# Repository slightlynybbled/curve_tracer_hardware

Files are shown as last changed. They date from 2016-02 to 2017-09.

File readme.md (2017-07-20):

# Purpose #

The purpose of this repository is to document the curve tracer project.  A
full description may be found at [for(embed)](http://www.forembed.com/project-curve-tracer-requirements.html).

# Project Repositories #

Be sure to check out the [firmware](https://github.com/slightlynybbled/curve_tracer_firmware) and 
[gui](https://github.com/slightlynybbled/curve_tracer_gui) repositories!

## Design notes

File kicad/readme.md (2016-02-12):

# Electronics #

This directory contains the schematics and PCB layout (KiCad)

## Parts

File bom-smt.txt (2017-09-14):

Item	Qty	Reference	Manufacturer	MPN	Description	Datasheet	
1	13	 C1, C7, C8, C9, C10, C11, C12, C13, C14, C24, C25, C26, C27	Yageo	CC0603ZRY5V7BB104	capacitor, 100nF, 0603		
2	12	 C2, C4, C6, C15, C16, C17, C18, C19, C20, C21, C22, C23	Yageo	CC0603ZRY5V7BB105	capacitor, 1uF, 0603		
3	2	 C3, C5	Kemet	C0603C470J3GACTU	capacitor, 47pF, 0603		
5	1	 P2	JAE Electronics	DX4R005JJ2R1800	Conn USB Micro-B		
6	1	 P3	Molex	0022284020	header, 0.1in, 2-pos		
7	1	 P4	Assmann WSW Components	A06-LC-TT	DIP socket, 2x3		
10	6	 R1, R2, R3, R7, R16, R21	Yageo	RC0603FR-0710KL	resistor, 10kohm, 0603		
11	1	 R12	Yageo	RC0603FR-0710RL	resistor, 10ohm, 0603		
12	12	 R4, R5, R6, R8, R11, R13, R14, R15, R17, R18, R19, R20	Yageo	RC0603FR-071KL	resistor, 1kohm, 0603		
13	2	 R9, R10	Yageo	RC0603FR-0727RL	resistor, 27ohm, 0603		
14	1	 U1	Microchip	MCP6L04T-E/ST	Opamp 1MHz, Quad, TSSOP-14		
15	1	 U2	Microchip, Inc.	PIC24FV16KM202-I/SS	Microcontroller		
16	1	 U3	FTDI	FT230XS-R	USB-to-UART, IC, SSOP-16

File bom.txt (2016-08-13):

Item	Qty	Reference	Manufacturer	MPN	Description	Datasheet	
1	13	 C1, C7, C8, C9, C10, C11, C12, C13, C14, C24, C25, C26, C27	Yageo	CC0603ZRY5V7BB104	capacitor, 100nF, 0603		
2	12	 C2, C4, C6, C15, C16, C17, C18, C19, C20, C21, C22, C23	Yageo	CC0603ZRY5V7BB105	capacitor, 1uF, 0603		
3	2	 C3, C5	Kemet	C0603C470J3GACTU	capacitor, 47pF, 0603		
4	11	 P1, W2, W3, W1, W4, W5, W8, W9, P5, P9, P8			programming header		
5	1	 P2	JAE Electronics	DX4R005JJ2R1800	Conn USB Micro-B		
6	1	 P3	Molex	0022284020	header, 0.1in, 2-pos		
7	1	 P4	Assmann WSW Components	A06-LC-TT	DIP socket, 2x3		
8	1	 P6	B&K Precision	CT3150-2	jack, safety, red		
9	1	 P7	B&K Precision	CT3150-0	jack, safety, black		
10	6	 R1, R2, R3, R7, R16, R21	Yageo	RC0603FR-0710KL	resistor, 10kohm, 0603		
11	1	 R12	Yageo	RC0603FR-0710RL	resistor, 10ohm, 0603		
12	12	 R4, R5, R6, R8, R11, R13, R14, R15, R17, R18, R19, R20	Yageo	RC0603FR-071KL	resistor, 1kohm, 0603		
13	2	 R9, R10	Yageo	RC0603FR-0727RL	resistor, 27ohm, 0603		
14	1	 U1	Microchip	MCP6L04T-E/ST	Opamp 1MHz, Quad, TSSOP-14		
15	1	 U2	Microchip, Inc.	PIC24FV16KM202-I/SS	Microcontroller		
16	1	 U3	FTDI	FT230XS-R	USB-to-UART, IC, SSOP-16

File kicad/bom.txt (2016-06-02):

Item	Qty	Reference	Manufacturer	MPN	Description	Datasheet	
1	9	 C1, C7, C8, C9, C10, C11, C12, C13, C14	Yageo	CC0603ZRY5V7BB104	capacitor, 100nF, 0603		
2	12	 C2, C4, C6, C15, C16, C17, C18, C19, C20, C21, C22, C23	Yageo	CC0603ZRY5V7BB105	capacitor, 1uF, 0603		
3	2	 C3, C5	Kemet	C0603C470J3GACTU	capacitor, 47pF, 0603		
4	11	 P1, W2, W3, W6, W7, W1, W4, W5, W8, W9, W10					
5	1	 P2	JAE Electronics	DX4R005JJ2R1800	Conn USB Micro-B		
6	1	 P3	On Shore Technology, Inc.	OSTTC032162	terminal block, 5.08mm, 3pos		
7	1	 P4	Assmann WSW Components	A06-LC-TT	DIP socket		
8	5	 R1, R2, R3, R7, R16	Yageo	RC0603FR-0710KL	resistor, 10kohm, 0603		
9	1	 R12	Yageo	RC0603FR-0710RL	resistor, 10ohm, 0603		
10	8	 R4, R5, R6, R8, R11, R13, R14, R15	Yageo	RC0603FR-071KL	resistor, 1kohm, 0603		
11	2	 R9, R10	Yageo	RC0603FR-0727RL	resistor, 27ohm, 0603		
12	1	 U1	Microchip	MCP6L04T-I/ST	Opamp 1MHz, Quad, TSSOP-14		
13	1	 U2	Microchip, Inc.	PIC24FV16KM202	Microcontroller		
14	1	 U3	FTDI	FT230XS-R	USB-to-UART, IC, SSOP-16

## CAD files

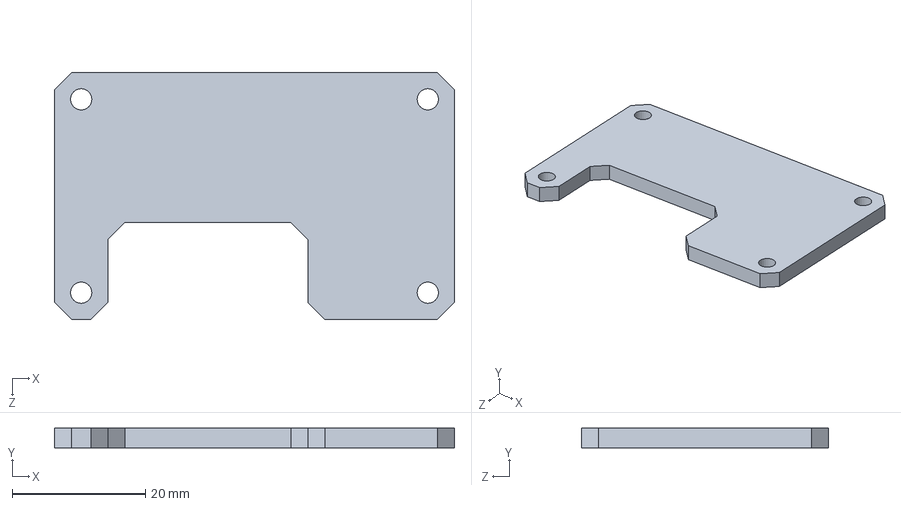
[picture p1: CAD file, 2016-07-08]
cad/solidworks/case_top.SLDPRT
60.0 x 3.00 x 37.0 mm

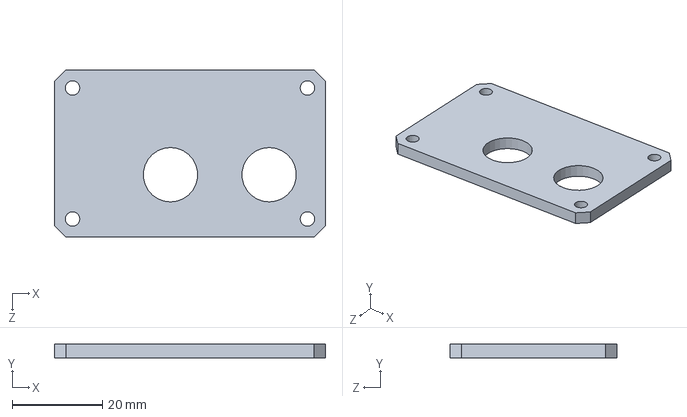
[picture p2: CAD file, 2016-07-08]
cad/solidworks/case_bottom.SLDPRT
60.0 x 3.00 x 37.0 mm

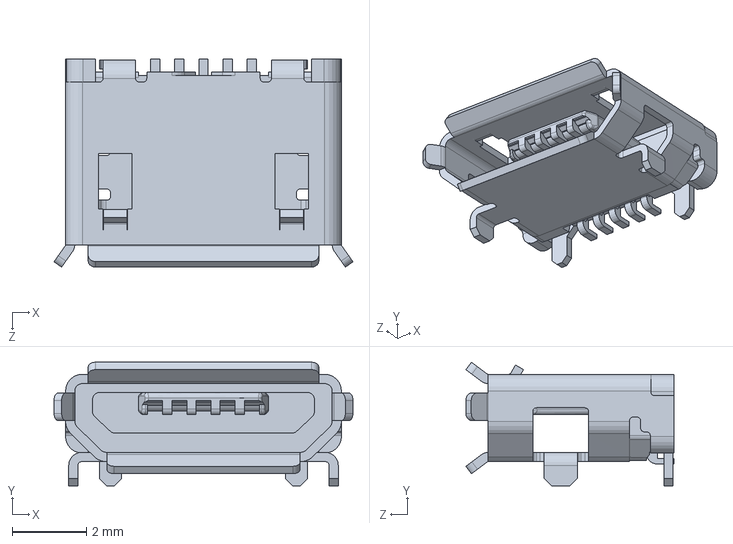
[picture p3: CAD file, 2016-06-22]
cad/solidworks/DX4R005JJ2R1800.SLDPRT
8.04 x 3.33 x 5.60 mm

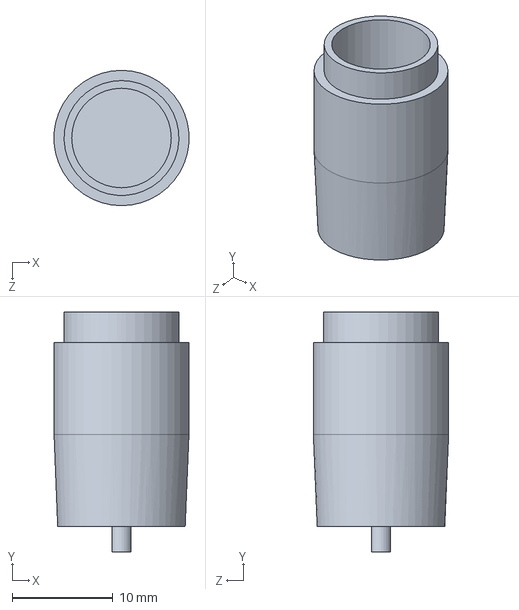
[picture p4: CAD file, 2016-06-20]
cad/solidworks/ct3150-0.SLDPRT
13.4 x 23.9 x 13.5 mm

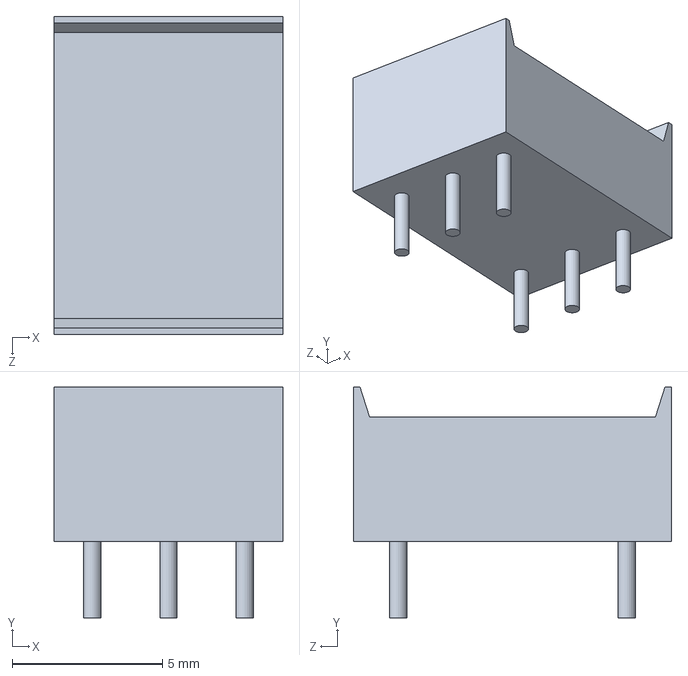
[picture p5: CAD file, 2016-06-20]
cad/solidworks/A06-LC-TT.SLDPRT
7.62 x 7.69 x 10.6 mm

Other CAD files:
cad/solidworks/ct3150-2.SLDPRT

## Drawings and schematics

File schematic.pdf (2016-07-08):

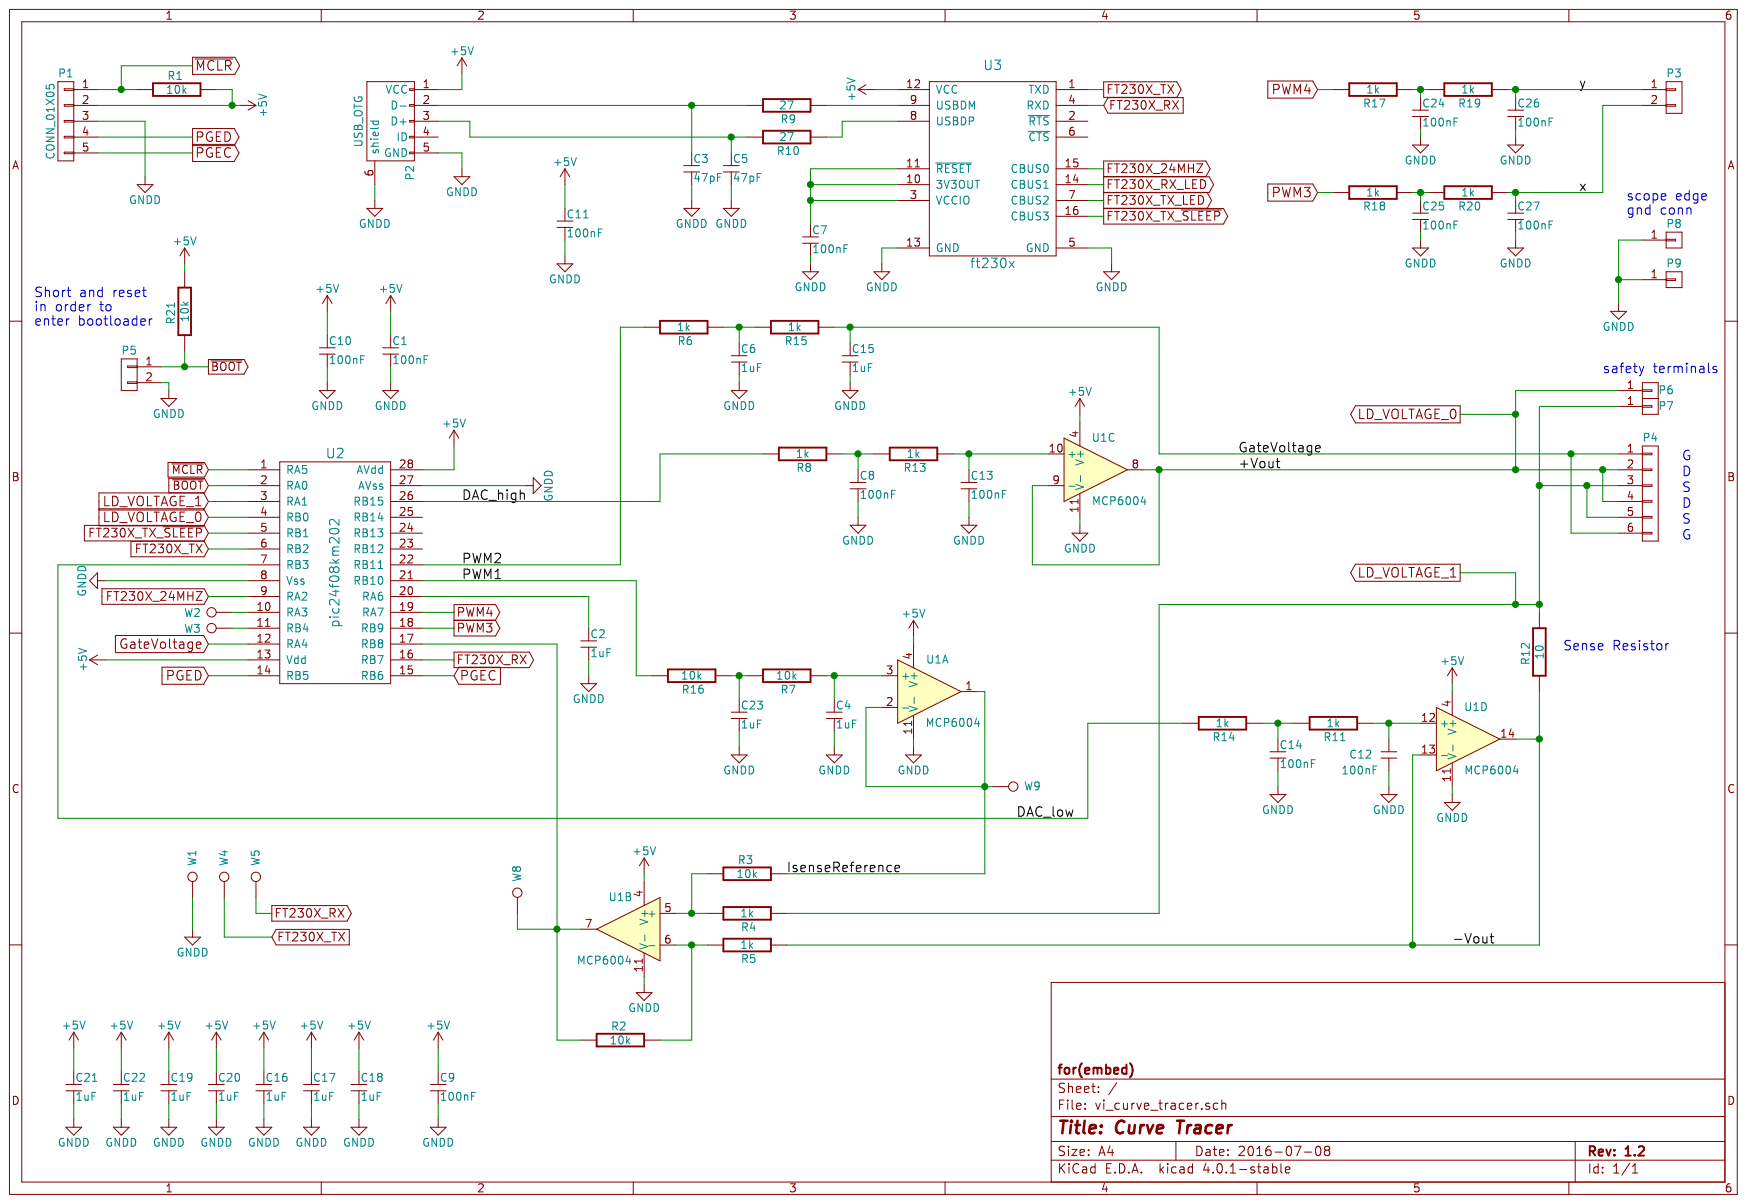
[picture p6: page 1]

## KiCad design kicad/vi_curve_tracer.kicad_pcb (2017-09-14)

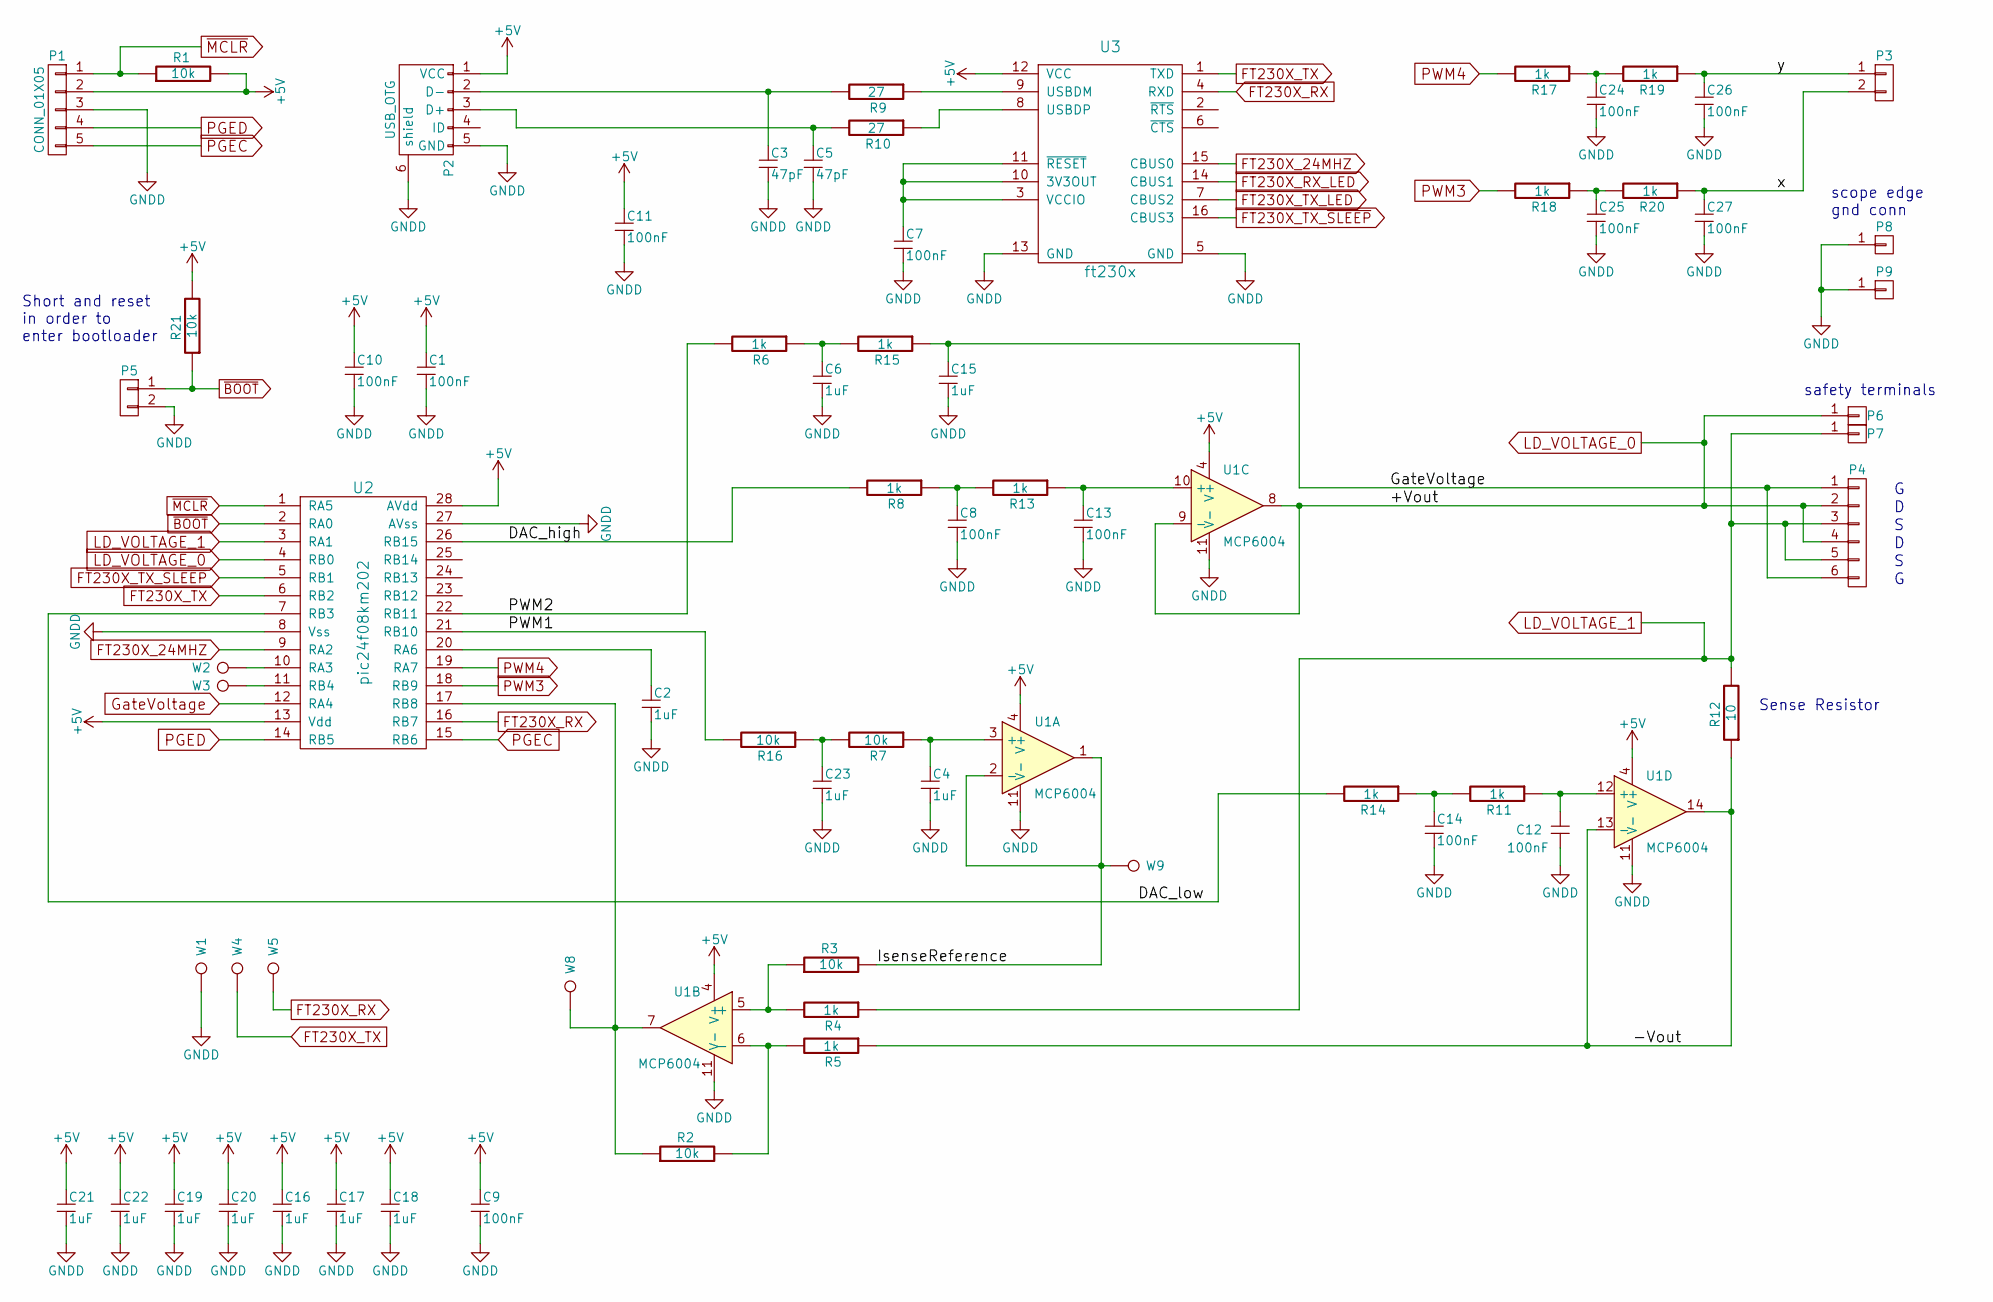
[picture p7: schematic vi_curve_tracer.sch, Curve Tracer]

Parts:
C1, C7, C8, C9, C10, C11, C12, C13, C14, C24, C25, C26, C27: 100nF; SM_0603; MPN CC0603ZRY5V7BB104
C2, C4, C6, C15, C16, C17, C18, C19, C20, C21, C22, C23: 1uF; SM_0603; MPN CC0603ZRY5V7BB105
C3, C5: 47pF; SM_0603; MPN C0603C470J3GACTU
P1: CONN_01X05; CONN_1x5_0.1in
P2: USB_OTG; CONN_USB; MPN DX4R005JJ2R1800
P3: CONN_01X02; CON_1x2_0.1in; MPN 0022284020
P4: CONN_01X06; CONN_2x3_SOCKET; MPN A06-LC-TT
P5: CONN_01X02; Pin_Header_Straight_1x02
P6: CONN_01X01; CONN_1x1_CT3150; MPN CT3150-2
P7: CONN_01X01; CONN_1x1_CT3150; MPN CT3150-0
P8, P9: CONN_01X01; CONN_1x1_EDGE_SCOPE_GND
R1, R2, R3, R7, R16, R21: 10k; SM_0603; MPN RC0603FR-0710KL
R4, R5, R6, R8, R11, R13, R14, R15, R17, R18, R19, R20: 1k; SM_0603; MPN RC0603FR-071KL
R9, R10: 27; SM_0603; MPN RC0603FR-0727RL
R12: 10; SM_0603; MPN RC0603FR-0710RL
U1: MCP6004; SSOP-14; MPN MCP6L04T-E/ST
U2: pic24f08km202; SSOP-28; MPN PIC24FV16KM202-I/SS
U3: ft230x; SOIC-16; MPN FT230XS-R
W1, W2, W3, W4, W5, W8, W9: TEST_1P; Measurement_Point_Round-SMD-Pad_Small

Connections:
+5V: C1.1, C9.1, C10.1, C11.1, C16.1, C17.1, C18.1, C19.1, C20.1, C21.1, C22.1, P1.2, P2.1 (VCC), R1.2, R21.2, U1.4 (V+), U2.13 (Vdd), U2.28 (AVdd), U3.12 (VCC)
/-Vout: R5.1, R12.1, U1.13 (-), U1.14
/DAC_high: R8.2, U2.26 (RB15)
/DAC_low: R14.2, U2.7 (RB3)
/IsenseReference: R3.2, U1.1, U1.2 (-), W9.1
/PWM1: R16.2, U2.21 (RB10)
/PWM2: R6.2, U2.22 (RB11)
/x: C27.1, P3.2, R20.1
/y: C26.1, P3.1, R19.1
FT230X_24MHZ: U2.9 (RA2), U3.15 (CBUS0)
FT230X_RX: U2.16 (RB7), U3.4 (RXD), W5.1
FT230X_TX: U2.6 (RB2), U3.1 (TXD), W4.1
FT230X_TX_~SLEEP: U2.5 (RB1), U3.16 (CBUS3)
GNDD: C1.2, C2.2, C3.2, C4.2, C5.2, C6.2, C7.2, C8.2, C9.2, C10.2, C11.2, C12.2, C13.2, C14.2, C15.2, C16.2, C17.2, C18.2, C19.2, C20.2, C21.2, C22.2, C23.2, C24.2, C25.2, C26.2, C27.2, P1.3, P2.5 (GND), P2.6 (shield), P5.2, P8.1, P9.1, U1.11 (V-), U2.8 (Vss), U2.27 (AVss), U3.5 (GND), U3.13 (GND), W1.1
GateVoltage: C15.1, P4.1, P4.6, R15.1, U2.12 (RA4)
LD_VOLTAGE_0: P4.2, P4.4, P6.1, U1.8, U1.9 (-), U2.4 (RB0)
LD_VOLTAGE_1: P4.3, P4.5, P7.1, R4.1, R12.2, U2.3 (RA1)
unnamed: C2.1, U2.20 (RA6)
unnamed: C3.1, P2.2 (D-), R9.2
unnamed: C4.1, R7.1, U1.3 (+)
unnamed: C5.1, P2.3 (D+), R10.2
unnamed: C6.1, R6.1, R15.2
unnamed: C7.1, U3.3 (VCCIO), U3.10 (3V3OUT), U3.11 (~RESET)
unnamed: C8.1, R8.1, R13.2
unnamed: C12.1, R11.1, U1.12 (+)
unnamed: C13.1, R13.1, U1.10 (+)
unnamed: C14.1, R11.2, R14.1
unnamed: C23.1, R7.2, R16.1
unnamed: C24.1, R17.1, R19.2
unnamed: C25.1, R18.1, R20.2
unnamed: R2.1, U1.7, U2.17 (RB8), W8.1
unnamed: R2.2, R5.2, U1.6 (-)
unnamed: R3.1, R4.2, U1.5 (+)
unnamed: R9.1, U3.9 (USBDM)
unnamed: R10.1, U3.8 (USBDP)
unnamed: U2.10 (RA3), W2.1
unnamed: U2.11 (RB4), W3.1
PGEC: P1.5, U2.15 (RB6)
PGED: P1.4, U2.14 (RB5)
PWM3: R18.2, U2.18 (RB9)
PWM4: R17.2, U2.19 (RA7)
~BOOT: P5.1, R21.1, U2.2 (RA0)
~MCLR: P1.1, R1.1, U2.1 (RA5)

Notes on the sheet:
Sense Resistor
Short and reset in order to enter bootloader
safety terminals
scope edge gnd conn

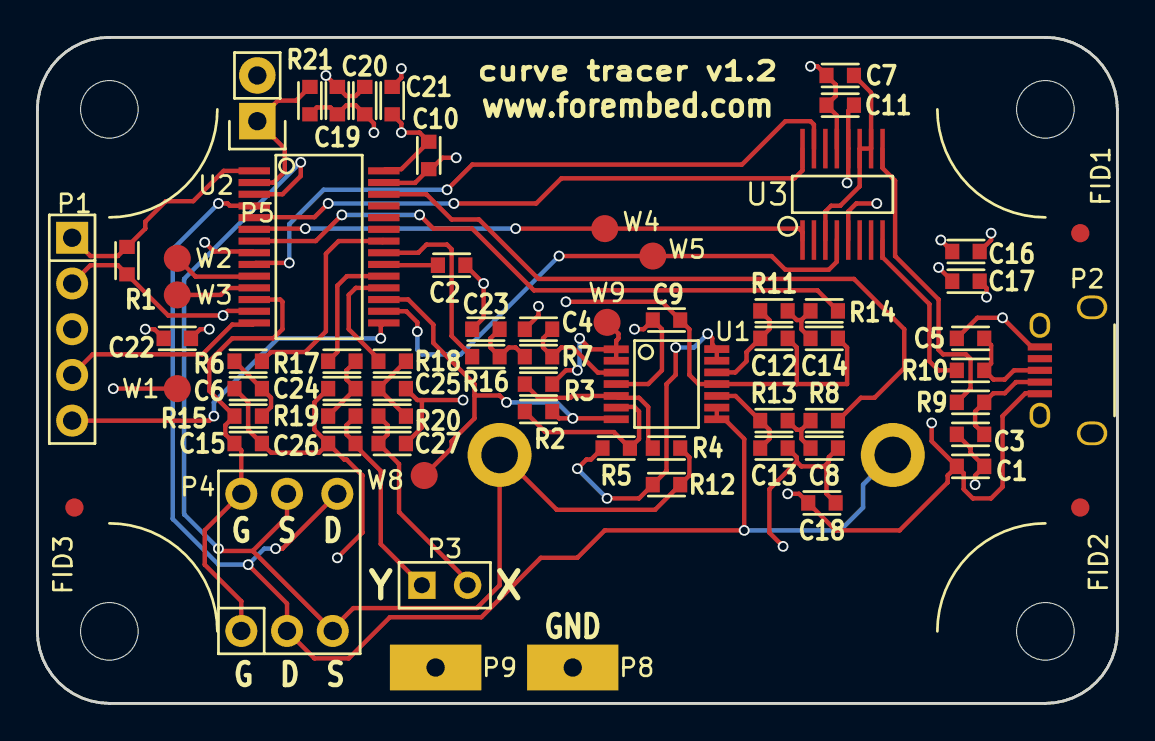
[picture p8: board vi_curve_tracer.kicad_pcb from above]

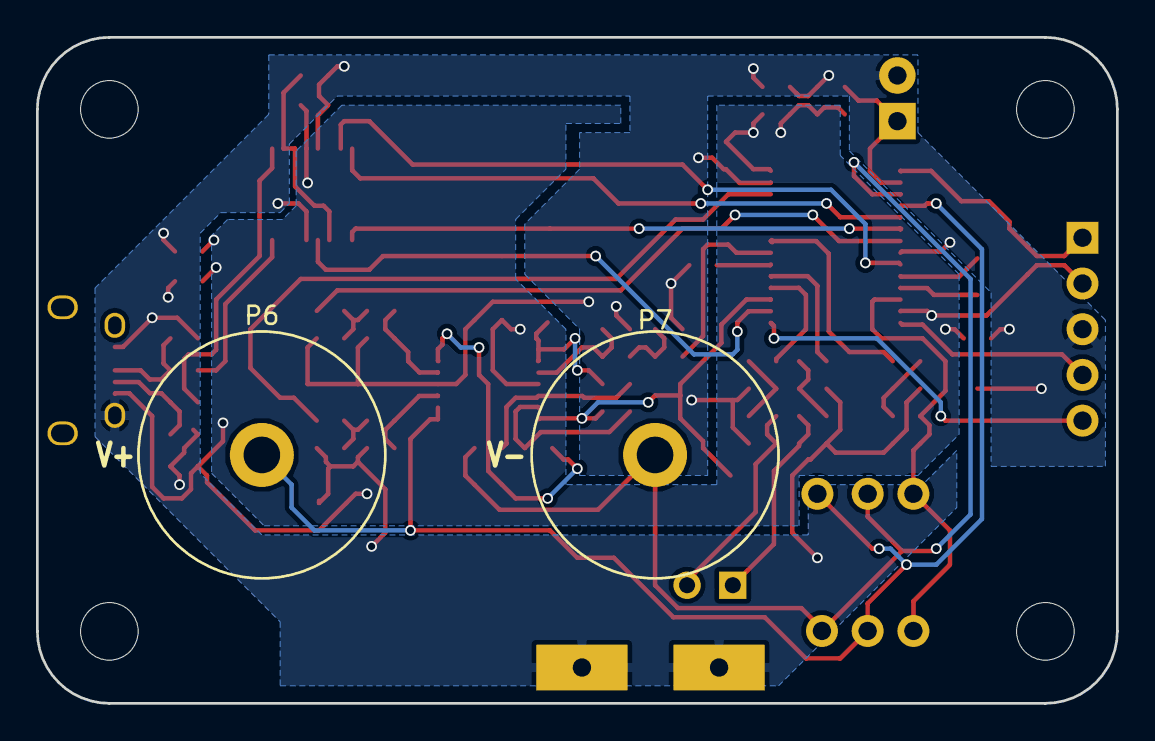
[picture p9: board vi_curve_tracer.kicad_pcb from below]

Board: 2 copper layers, 60.0 x 37.0 mm, 71 parts (2 on the bottom side), 43 nets.

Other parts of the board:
FID1, FID2, FID3: fiducial
SOB: case_sickOfBeige_60x37

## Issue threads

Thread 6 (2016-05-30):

Add 'self calibration' or 'zero' mode

slightlynybbled, 2016-05-30:
There is a potential offset on the current output that may be the result of several circuit imperfections.  On power up - and on command - the software should adjust the PWM1 output duty cycle so that the current sense output is at a current corresponding to 0mA, or 1.65V.

Closed 2016-06-02.

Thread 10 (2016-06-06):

Add lower sample count in order to increase the frequency

slightlynybbled, 2016-06-06:
At present, the ADC sample rate is limiting the upper frequency to ~100Hz because of the number of samples per sine waveform.  If the number of samples were halved, then the high-end frequency would double.

slightlynybbled, 2016-06-14:
Unnecessary at this time.

Closed 2016-06-14.

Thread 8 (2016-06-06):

Add ground reference terminal to P3

slightlynybbled, 2016-06-06:
Although not necessary for the curve tracer, it might be nice if the board is to be re-purposed as some sort of waveform generator.

Closed 2016-06-06.

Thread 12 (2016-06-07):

Add waveform generator mode

slightlynybbled, 2016-06-07:
This mode would ignore the A/D and generate waveforms only.  By ignoring the A/D, the waveforms could be much faster than the 94Hz limit currently imposed by the A/D

slightlynybbled, 2016-06-14:
This issue will now be tracked on the [firmware repository](https://github.com/slightlynybbled/curve_tracer_firmware).

Closed 2016-06-14.

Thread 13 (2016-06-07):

Add outputs for scope with xy mode

slightlynybbled, 2016-06-07:
Use pins 18 and 19 to generate a PWM signal and filter that signal.

slightlynybbled, 2016-06-09:
C code and hardware have been added to address this.

Closed 2016-06-09.

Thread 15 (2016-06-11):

Add gate-voltage scan mode

slightlynybbled, 2016-06-11:

slightlynybbled, 2016-06-14:
Refactored repository.  GUI issues are now tracked in the [GUI repository](https://github.com/slightlynybbled/curve_tracer_gui)

Closed 2016-06-14.

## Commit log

2016-02-12 Adding all electronic files relating to the curve tracer project.
    [vi_curve_tracer.kicad_pcb, vi_curve_tracer.sch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]
2016-02-14 Added sine wave generation to the timer interrupt, reduced timer interrupt frequency
2016-02-25 Have PWM output working, frequency appears off by a factor of 2
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2016-03-01 Have ADC working as a multiplexed input, not functioning correctly yet
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2016-03-02 Now making low-frequency measurements of hi-Z outputs while maintaining high-frequency measurements of the other three voltages
2016-03-02 All ADC interrupts occur within one T1 interrupt
2016-03-02 Made the schematic more closely resemble the rework performed.
    [_saved_vi_curve_tracer.sch, vi_curve_tracer.sch]
2016-03-02 Saved schematic w/ program closed
    [_saved_vi_curve_tracer.sch, vi_curve_tracer.sch]
2016-03-02 Added some test data
    [loadCurrent.csv, loadVoltage.csv]
2016-03-04 Corrected CCT3 interrupt from CCP3 interrupt
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2016-03-20 Moved DIO and UART libraries to their own files
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2016-03-22 Moved the uart code to the telemetry lib. Modified main so that telemetry works as a transmitter
2016-03-23 Re-added UART interface - removing references to telemetry lib
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2016-03-23 Modified UART lib to be compatible with the new circular buffer format
2016-03-24 Modified main.c to use framing instead of the UART directly
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2016-04-05 Adding Python framework classes to easily handle the data coming into the serial port on the PC side
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2016-04-10 Added ability for frame to write incrementally to the UART buffer
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2016-04-28 Made some changes to schematic values, added PDF
    [vi_curve_tracer.sch]
2016-04-29 Added Dispatch drivers to this code for configuration purposes
2016-04-29 Plotting voltage to find potential issues
2016-05-03 Added electronics files, nearly complete
    [_order_pcb.csv, _saved_vi_curve_tracer.sch, bom_pcb.csv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]
2016-05-05 Updated electronics with most recent layout and schematic
    [_saved_vi_curve_tracer.sch, vi_curve_tracer.kicad_pcb, vi_curve_tracer.sch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]
2016-05-18 Added error messages at compile time when the UART buffers are inappropriately sized.
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2016-05-23 Removed old test files, changed 'code' directory to 'c' directory
    [loadCurrent.csv, loadVoltage.csv]
2016-05-23 Changed part to the industrial temp range
    [vi_curve_tracer.sch]
2016-05-26 Removed unnecessary electronics files
    [_order_pcb.csv, bom_pcb.csv]
2016-05-27 #4 Port complete for C code, had to move DAC outputs to opamp outputs on board to improve impedance
    [vi_curve_tracer.kicad_pcb, vi_curve_tracer.sch]
2016-05-27 Added a small attenuation factor for the output sine wave in order to avoid saturating the opamp output. This mildly limits the range of the output voltage, but vastly decreases harmonics.
2016-05-27 Changed filter resistors to 3.3k
    [vi_curve_tracer.sch]
2016-05-27 Corrected y-axis label
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2016-05-30 Corrected DAC sample rate to ADC sample rate
2016-05-30 Changed vertical scaling from 500uA/div to 5mA/div by reducing opamp gain and by changing the label in the GUI
    [vi_curve_tracer.sch]
2016-05-30 Changed R7 to increase filter effectiveness
    [vi_curve_tracer.sch]
2016-05-30 Removed attenuation factor - as hardware filtering became more accurate, the attenuation became unnecessary
2016-05-30 Increased the output filter frequency cutoff
    [vi_curve_tracer.sch]
2016-06-02 Minor rev of electronics, added BOM
    [vi_curve_tracer.kicad_pcb, vi_curve_tracer.sch]
2016-06-02 See #6 - Added functions to send and receive the calibration directive from the Python script
2016-06-02 Fixes #6 - Offset calibration complete and working
2016-06-02 See #5 - Added manual setting of gate voltage
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2016-06-03 See #5 - Added patch wire to control the gate voltage
    [vi_curve_tracer.kicad_pcb, vi_curve_tracer.sch]
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2016-06-06 Fixes #8 - Added ground reference on the terminal block
    [vi_curve_tracer.kicad_pcb, vi_curve_tracer.sch]
2016-06-09 See #13 - Added XY outputs to hardware
    [vi_curve_tracer.kicad_pcb, vi_curve_tracer.sch]
2016-06-09 Closes #2, adds a read button that is not fully implemented yet (see #3)
2016-06-10 Appear to have solved a race condition that caused random points to be erased or written to the canvas due to multiple threads competing for that canvas. Needs more testing and scatter method needs t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
2016-06-11 Added extra header to short in case we want to add a bootloader later
    [vi_curve_tracer.kicad_pcb, vi_curve_tracer.sch]
2016-06-13 Slight adjustment of component placement
    [vi_curve_tracer.kicad_pcb]
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2016-06-14 See #16 - added basic images for the pause and play buttons
2016-06-14 Updated BOM items based on feedback from octopart, added fiducials to layout
    [vi_curve_tracer.kicad_pcb, vi_curve_tracer.sch]
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2016-06-14 Moved kicad files from 'electronics' to 'kicad' directory
    [vi_curve_tracer.kicad_pcb, vi_curve_tracer.sch]
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2016-06-14 Moved gerber files outside of the kicad directory
    [vi_curve_tracer-B.Cu.gbr, vi_curve_tracer-B.Mask.gbr, vi_curve_tracer-Edge.Cuts.gbr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]
2016-06-20 Added safety (multimeter) probes for maximimum compatiblity with likely components that the user already has
    [vi_curve_tracer-B.Cu.gbr, vi_curve_tracer-B.Mask.gbr, vi_curve_tracer-B.SilkS.gbr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]
2016-06-20 Added some CAD models to make visualization of case easier
    [A06-LC-TT.SLDPRT, OSTTC042162.SLDPRT, case_bottom.SLDPRT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]
2016-06-22 Minor part movement
    [vi_curve_tracer.kicad_pcb, vi_curve_tracer.sch]
2016-06-22 Modeling in solidworks, designing the case
    [DX4R005JJ2R1800.SLDPRT, case_bottom.SLDPRT, curve-tracer-pcba-1v1.SLDASM]
2016-07-08 Added features to allow connecting to oscilloscope easier, no change to function.
    [vi_curve_tracer.kicad_pcb, vi_curve_tracer.sch]
2016-07-08 Added new gerber files for v1.2
    [vi_curve_tracer-B.Cu.gbr, vi_curve_tracer-B.Mask.gbr, vi_curve_tracer-B.SilkS.gbr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]
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2016-07-08 Moved points to make case design a bit easier
    [vi_curve_tracer-B.Cu.gbr, vi_curve_tracer-B.Mask.gbr, vi_curve_tracer-B.SilkS.gbr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]
2016-07-08 Modified case design to make it easier to cut
    [OSTTC042162.SLDPRT, case_bottom.SLDPRT, case_top.SLDPRT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]
2016-08-13 Fixed BOM issue
    [vi_curve_tracer.sch]
2017-09-14 Added fiducial
    [vi_curve_tracer-B.Cu.gbr, vi_curve_tracer-B.Mask.gbr, vi_curve_tracer-B.SilkS.gbr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]
